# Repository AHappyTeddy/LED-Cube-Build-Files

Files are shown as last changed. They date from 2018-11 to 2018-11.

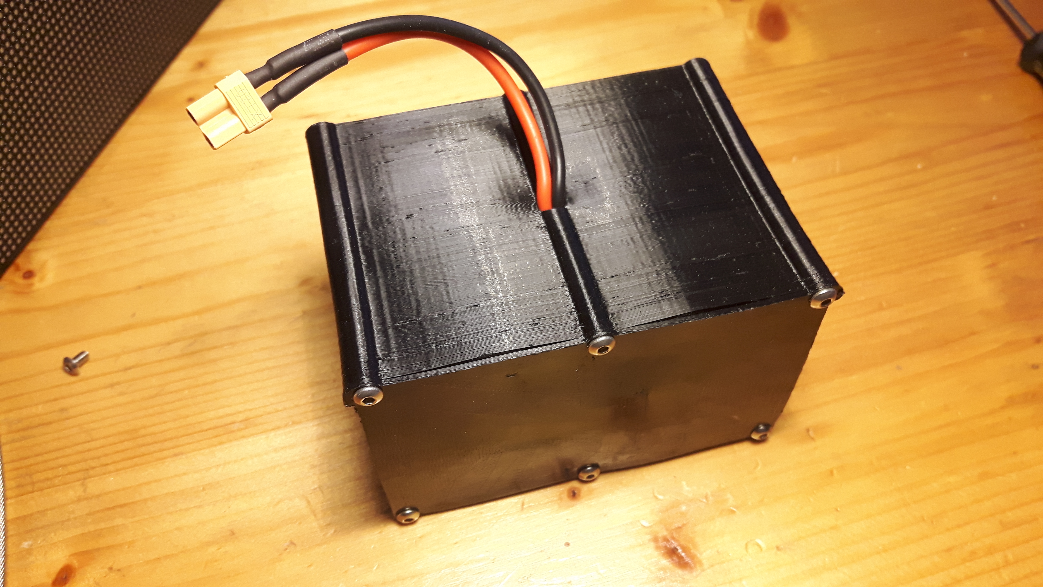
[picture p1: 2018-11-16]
pics/20181116_222736.jpg

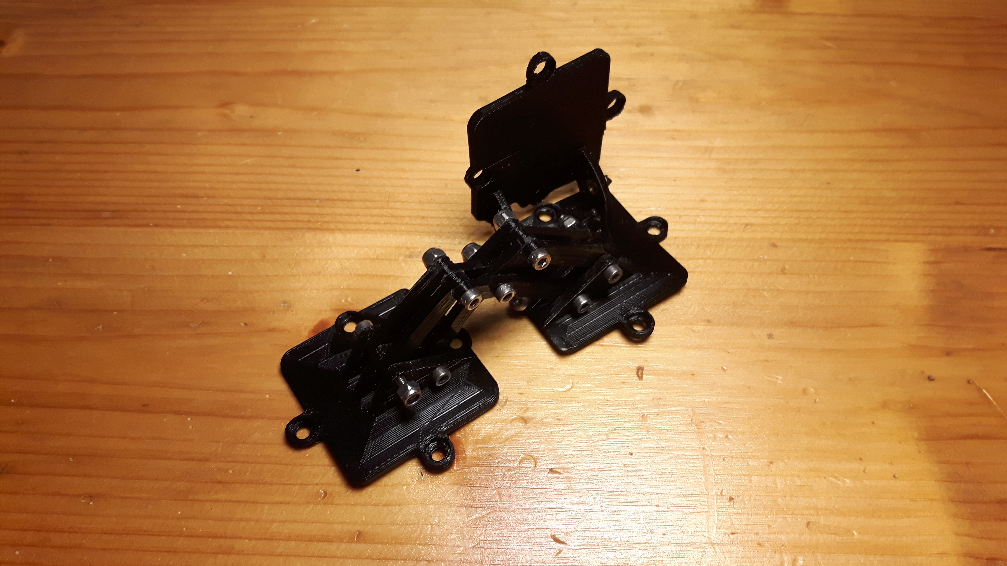
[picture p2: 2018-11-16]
pics/20181116_221448.jpg

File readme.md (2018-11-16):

# LED-Cube 3D Printing Files

these files are for building the LED-Cube with 160x160mm p2.5 LED panels. 

I labeled the files by what they are needed for and how many you need of them. On the layer 1 and 2 you can choose if you wanna 3D print or if you have access to a CNC mill it out of 3mm alu. If you can mill, I recommend it for following parts:

* 1x Layer 1 

* 1x Layer 2

* 8x Handel 1

* 8x Handel 2

* 6x DC DC Holder (if you going to use LM2596S)

Especially the layers have to hold some load and will deform a little with temperatures above 70° (PLA). The milled aluminum version can also buffer the heat better and it just looks much nicer :)

### To assemble it you need some additional stuff:

In case you've printed everything:

* at least 54x M3 Nuts 2mm high (in case u want to make it ultimate robust - twice that much)
* at least 60x M3x5 Bolts (very-strong-and-a-lot-more-work-to-built-cube - again twice that much)
* a couple M3x10 Bolts… Maybe 22x
* for the hinge:
  * 6x M2.5x14
  * 8x M2.5x18
  * 4x M2.5 self-locking nuts
* 14x M3 inserts
* 12x 10x5x2 neodym magnets

for the milled variant:

* 6x less M3 nuts 
* 6x M3 spacer nuts

and then all the electric stuff…

For printing i recommend to print the frames and the lid „upside down“ if you want to have a nice smooth finish where the panels go and the exact hight where the screws go.

For the assembly it's very important to put in the M3 nuts before screwing in the panels. Otherwise you'll get angry at yourself… For the not-strong-as-shit-variant you need nuts in every second hole. Look up the pics for further explanation. Also the DC-DC holders only need 2 Screws. For them you can use a washer to make sure the 10mm screw will not touch or even scratch the Panel.

After putting the nuts in the holes and putting the panels in the frames, you can start assembeling the cube by putting the panels an the corners together. After that you can put in the electric components and after that the two layers. The cube is designed in a way that you can put in the layers at the very last or to remove them without needing to disassemble the whole thing again.

if you have any further questions about the building or have some ideas how to make it better please send me a message on twitter [@1HappyTeddybear](https://twitter.com/1HappyTeddybear)

until then have fun with the cube… :)

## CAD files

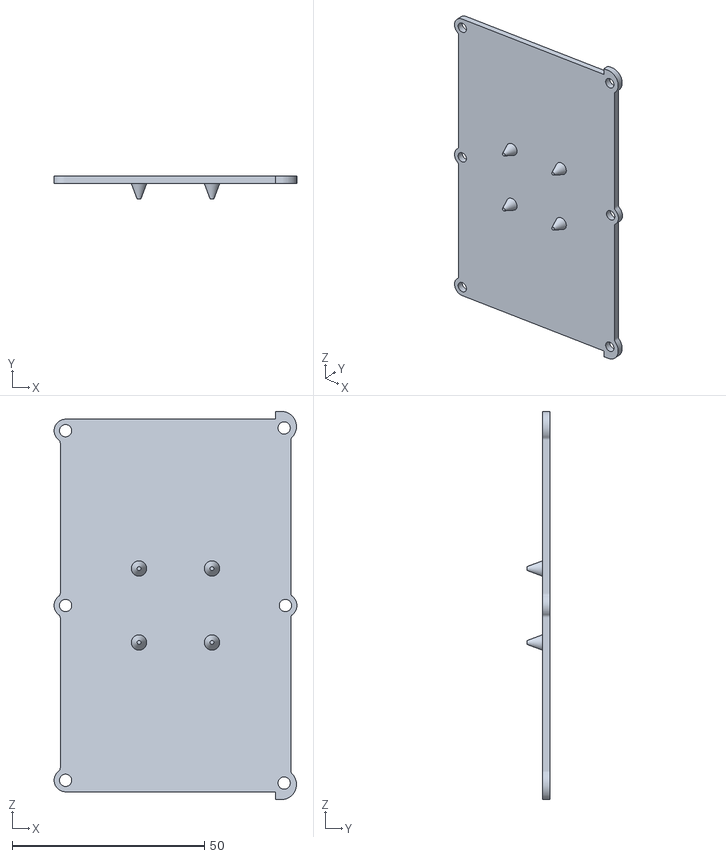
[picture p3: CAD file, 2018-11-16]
STL_Files/1x_akku_lid.stl
63.2 x 6.00 x 101.0

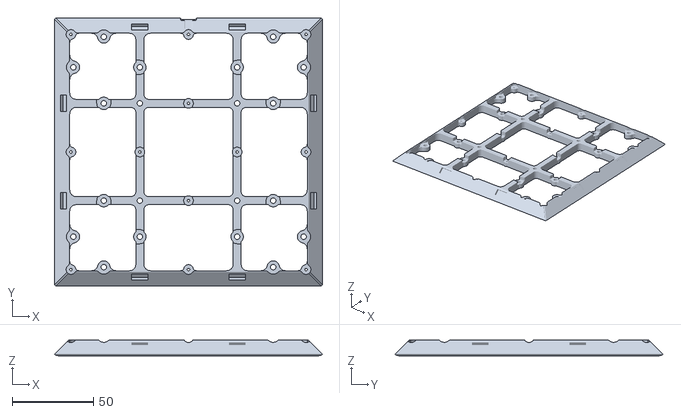
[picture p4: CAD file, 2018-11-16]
STL_Files/1x_Lid.stl
165.3 x 165.3 x 9.60

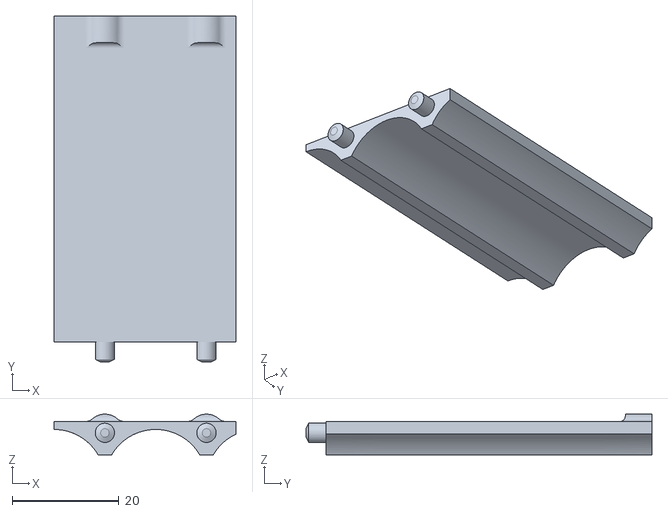
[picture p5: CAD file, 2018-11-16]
STL_Files/1x_akku_insert.stl
34.0 x 64.7 x 7.62

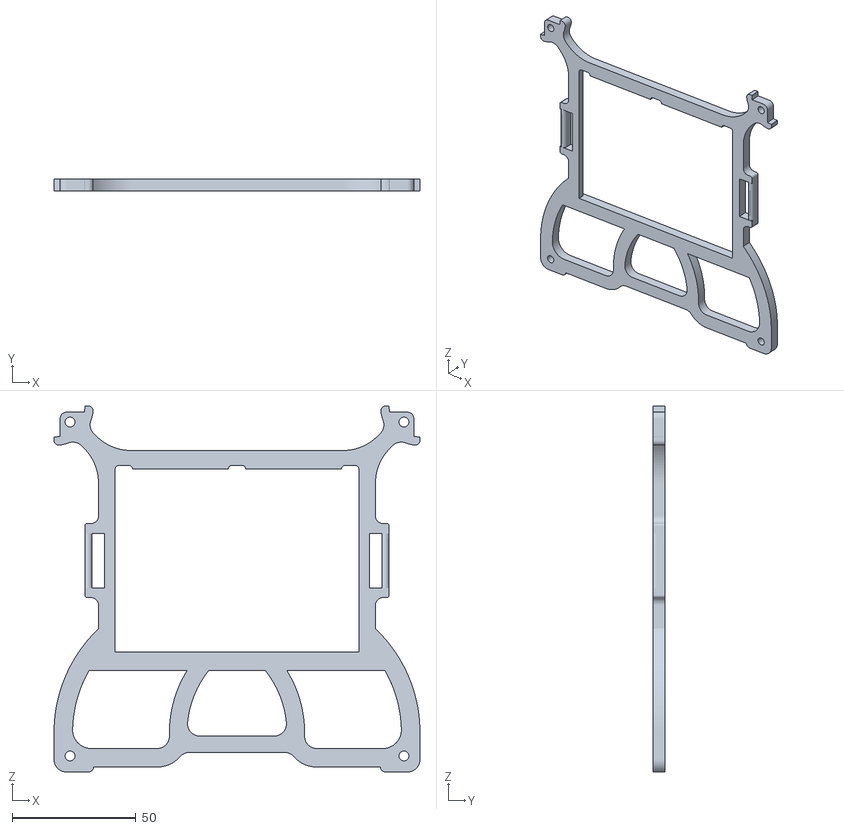
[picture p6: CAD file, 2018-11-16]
STL_Files/1x_Layer2.stl
148.0 x 5.00 x 148.0

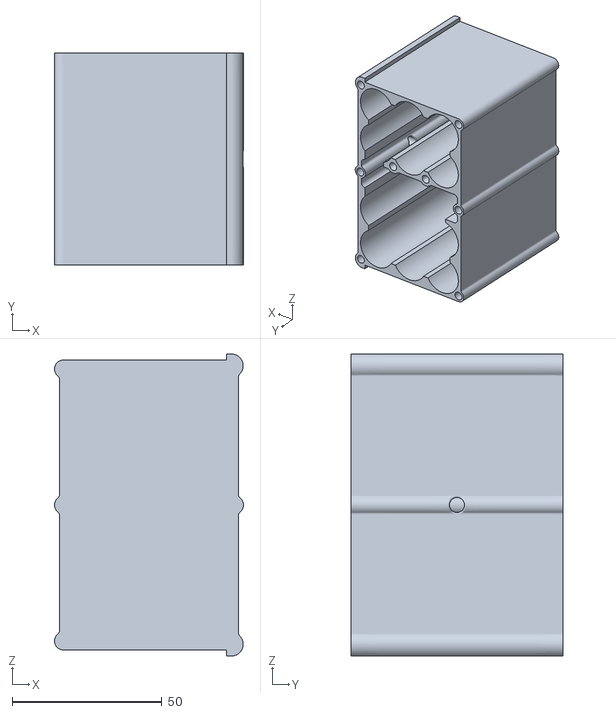
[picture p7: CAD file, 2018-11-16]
STL_Files/1x_akku_body.stl
63.2 x 71.0 x 101.0

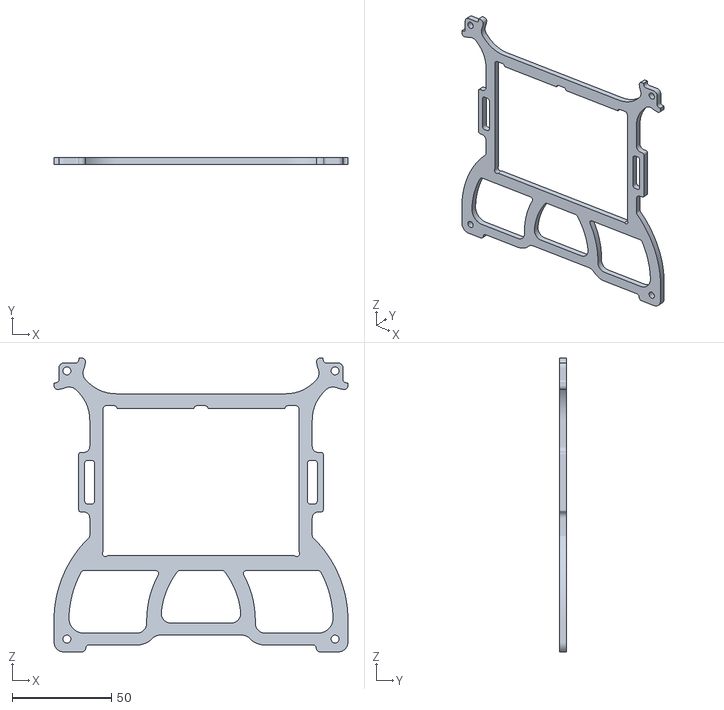
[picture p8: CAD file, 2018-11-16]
STL_Files/1x_Layer2 Alu Milled.stl
148.0 x 3.50 x 148.0

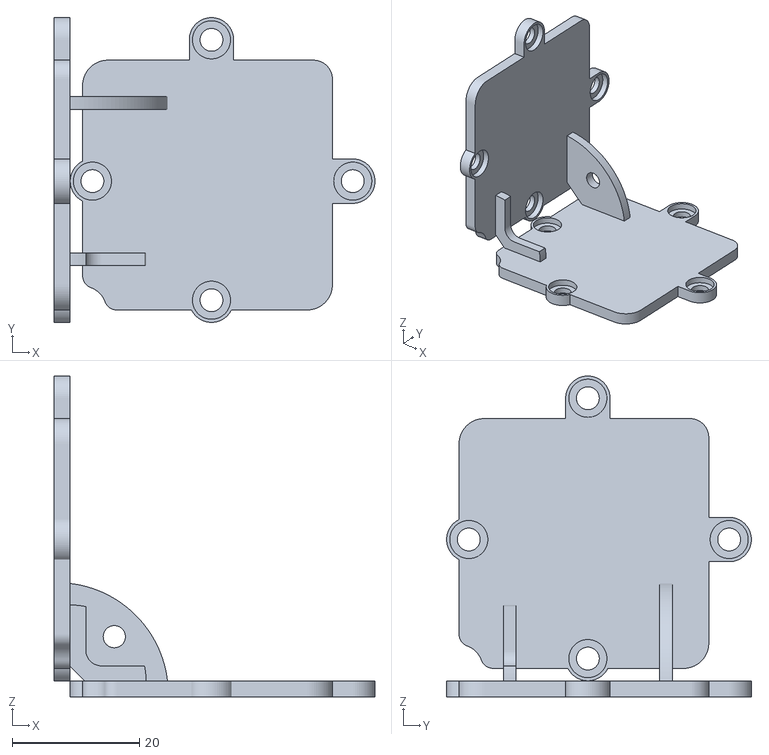
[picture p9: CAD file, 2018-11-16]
STL_Files/2x_Corner2.stl
50.6 x 48.0 x 50.5

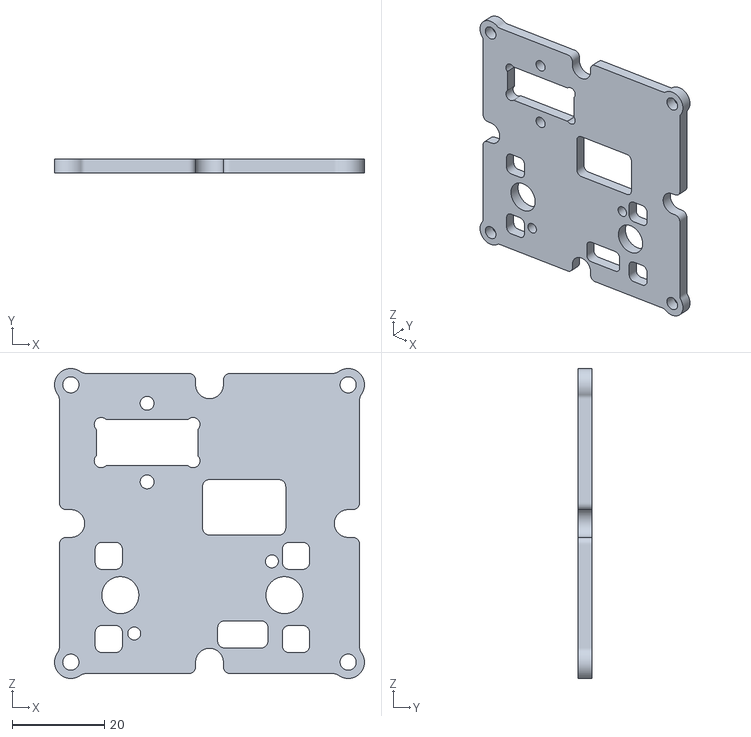
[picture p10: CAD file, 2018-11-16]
STL_Files/6x_DC_DC Holder.stl
67.1 x 3.00 x 67.1

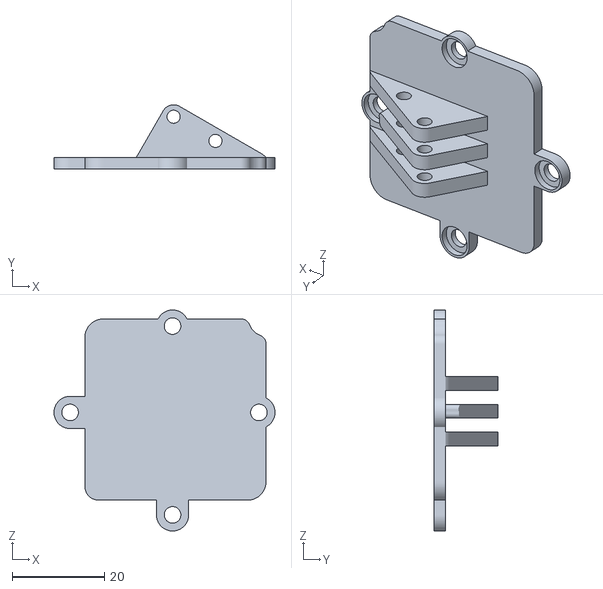
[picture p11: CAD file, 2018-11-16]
STL_Files/1x_HingeL2.stl
48.0 x 14.0 x 48.0

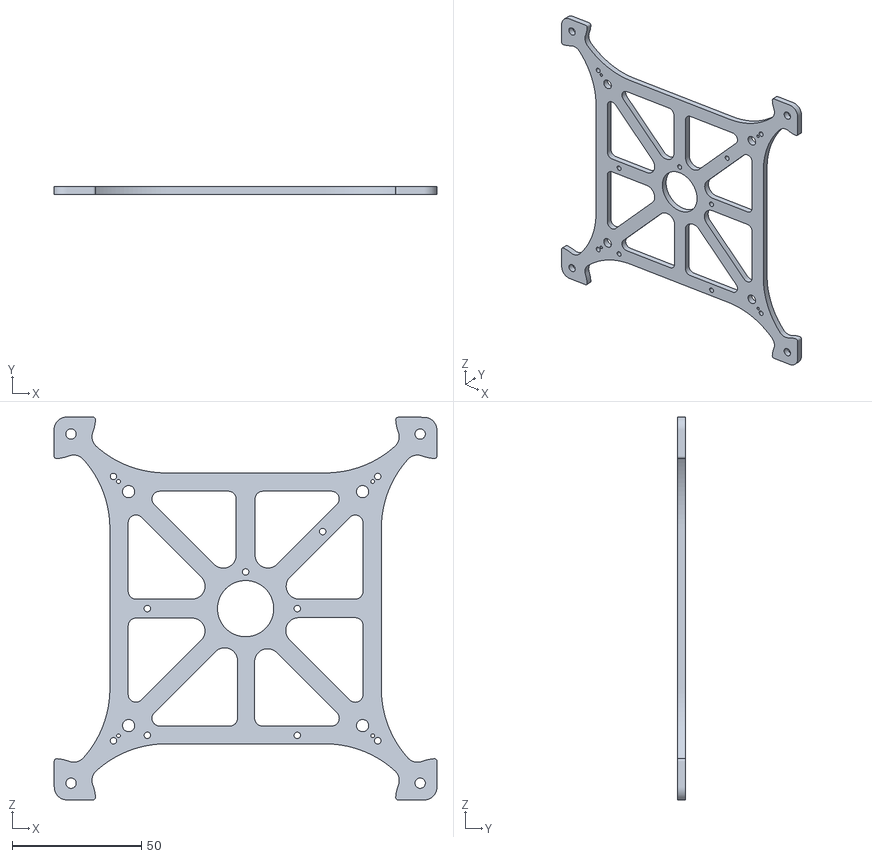
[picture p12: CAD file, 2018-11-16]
STL_Files/1x_Layer1 Alu milled.stl
148.1 x 3.00 x 148.1

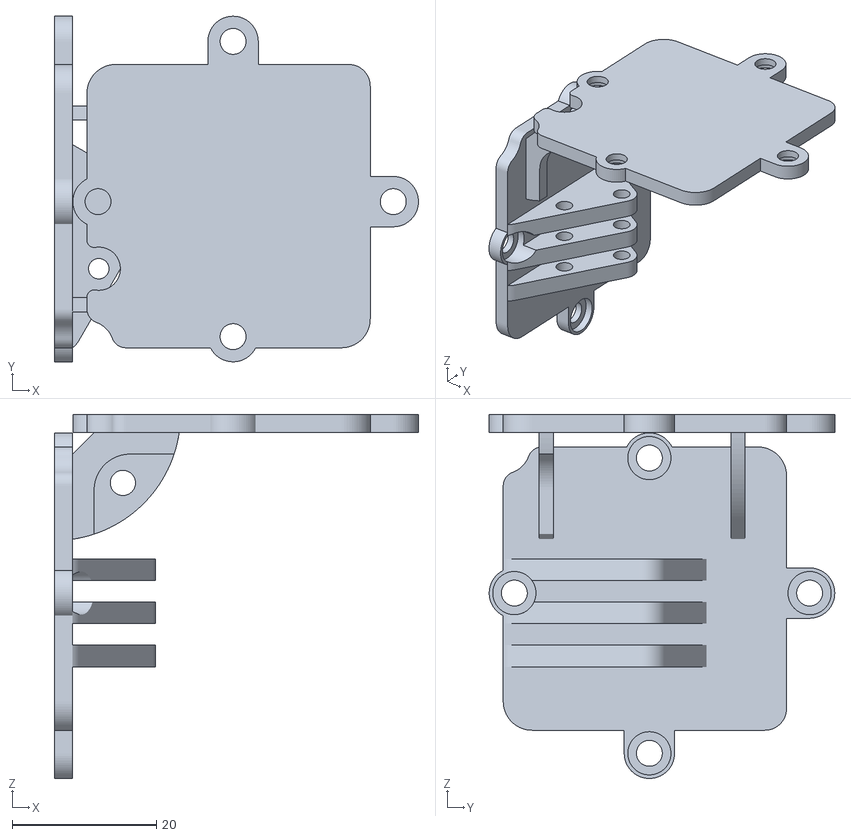
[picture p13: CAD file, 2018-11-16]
STL_Files/1x_HingeL1.stl
50.6 x 48.0 x 50.6

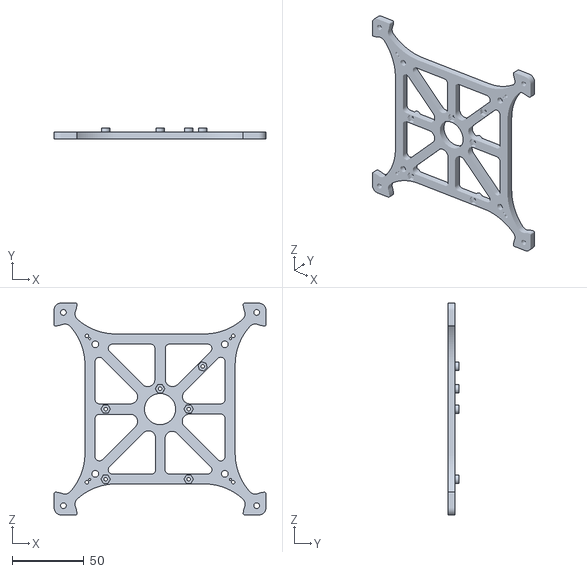
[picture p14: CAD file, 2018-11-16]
STL_Files/1x_Layer1.stl
148.1 x 8.00 x 148.1

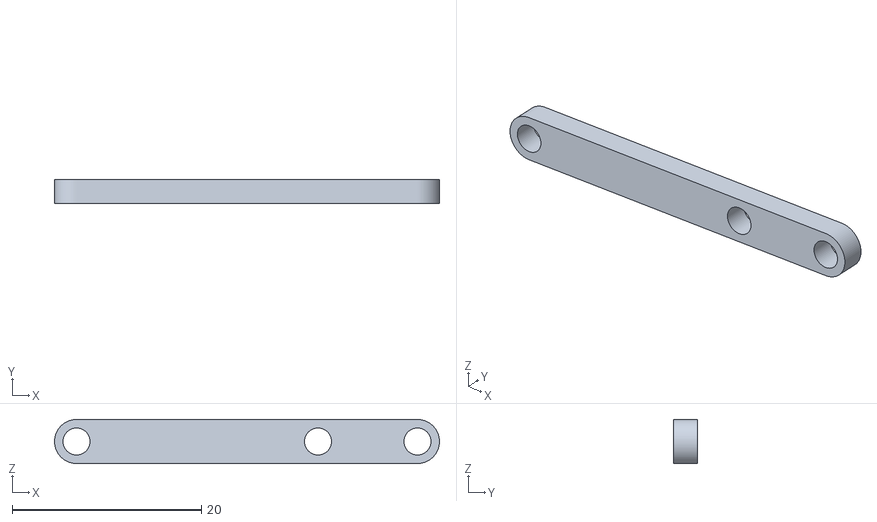
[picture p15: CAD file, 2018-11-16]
STL_Files/8x_Handle2.stl
40.7 x 2.50 x 4.65

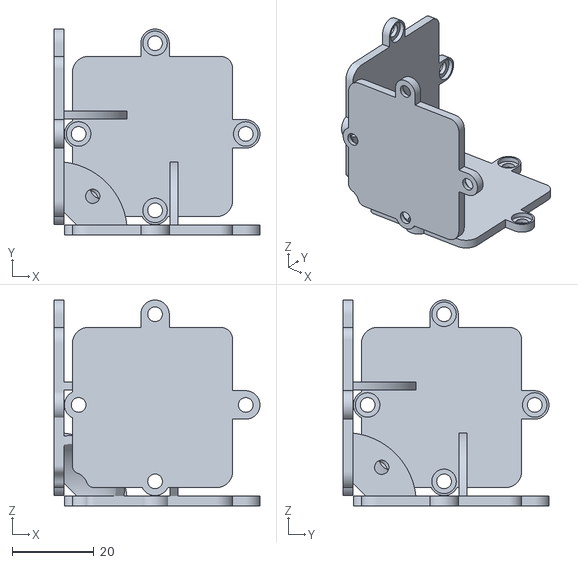
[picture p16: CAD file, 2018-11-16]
STL_Files/4x_Corner3.stl
50.6 x 50.6 x 50.5

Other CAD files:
STL_Files/1x_HingeR1.stl
STL_Files/5x_Frame.stl
STL_Files/1x_HingeR2.stl
STL_Files/8x_Handle1.stl

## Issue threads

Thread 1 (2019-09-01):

1x_Layer1 - Requires M3 nuts but raspberry pi holes are M2.5

greigs, 2019-09-01:
The screw posts also seem to be built for M2.5, so I think the only issue is the captured nut size is too large on 1x_Layer1.
